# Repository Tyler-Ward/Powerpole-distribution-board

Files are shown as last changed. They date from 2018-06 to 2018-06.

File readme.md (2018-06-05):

# DC Distribution board for Anderson power-pole connectors.

This project is a fused DC distribution board.
The design uses Anderson powerpoles and ATC/ATO fuses which are in common use in amateur radio.
Unlike other DIY solutions this uses the powerpole 45A PCB contacts rather than short stubs of solid wire crimped to the powerpoles.

## Required parts

* 1*PCB - Should be made on a 2oz copper board.
* 4*Acrylic layers - one of each layer 3 at 6mm thick and one at 3mm thick
* 6*Anderson power pole connector pairs with 45A PCB connectors.
* 6*ATO fuse holders
* 6*330ohm resistors
* 6*3mm LEDs - bidirectional LEDs allow for fuse failure indication for both source and sinks
* 6*0.1uF Bypass capacitors

## Production files and Assembly instructions

Production files for the PCB and acrylic can be found in the releases list on github.
Assembly instructions can be found at https://www.suws.org.uk/wiki/Powerpole_Distribution

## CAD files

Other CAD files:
Cad/ATCFuse.ipt
Cad/AcrylicLowerBottom.ipt
Cad/AcrylicLowerCore.ipt
Cad/AcrylicUpperCore.ipt
Cad/AcrylicUpperTop.ipt
Cad/Assembled.iam
Cad/Capacitor.ipt
Cad/FuseHolder.ipt
Cad/LED3mm.ipt
Cad/PCB.ipt
Cad/PopulatedPCB.iam
Cad/PowerPole45.ipt
Cad/Powerpole45APCBStraight.ipt
Cad/PowerpolePairWContacts.iam
Cad/Resistor.ipt

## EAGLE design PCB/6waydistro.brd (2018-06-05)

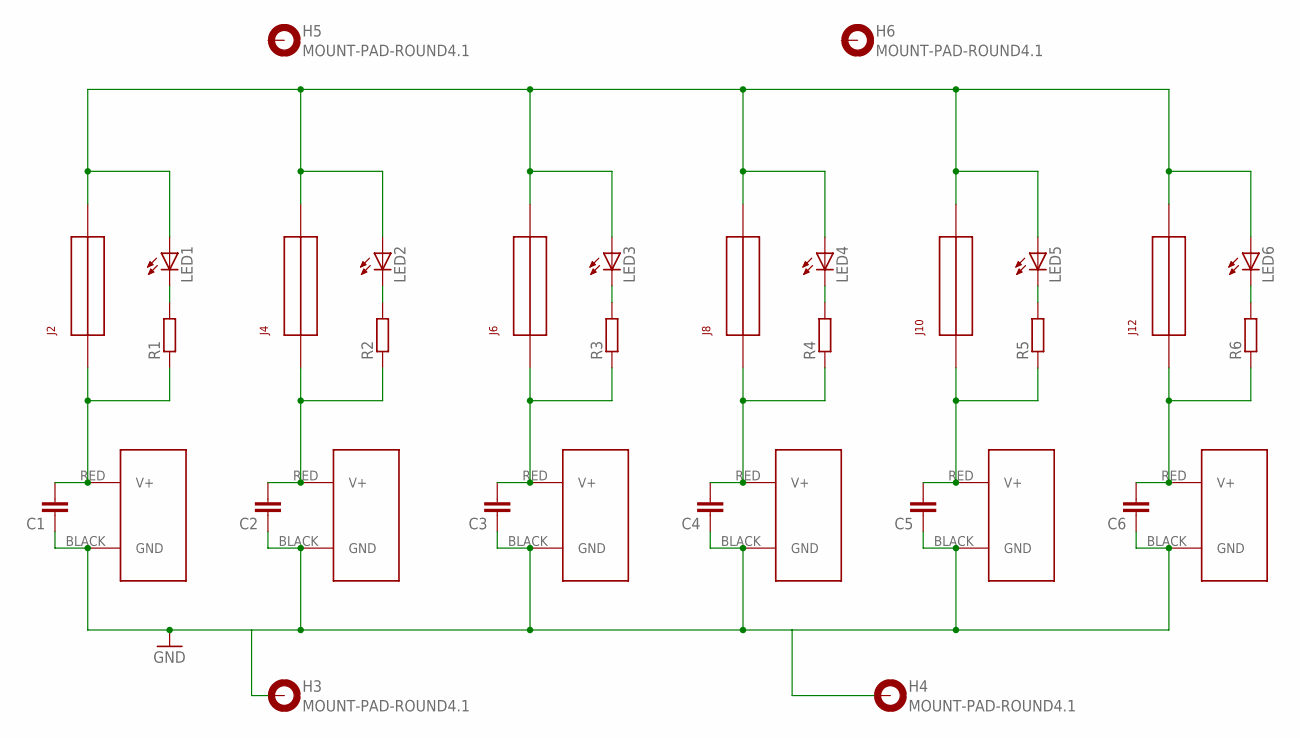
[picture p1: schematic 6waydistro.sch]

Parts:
C1, C2, C3, C4, C5, C6: C-EU050-025X075; C050-025X075
H3, H4, H5, H6: MOUNT-PAD-ROUND4.1; 4,1-PAD
J1, J3, J5, J7, J9, J11: POWERPOLE_POWER45A; POWERPOLE_PAIR_45A
J2, J4, J6, J8, J10, J12: FUSEATC; FUSE_ATC
LED1, LED2, LED3, LED4, LED5, LED6: LED3MM
R1, R2, R3, R4, R5, R6: R-EU_0204/7; 0204/7

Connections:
GND: C1.1, C2.1, C3.1, C4.1, C5.1, C6.1, H3.B4,1, H4.B4,1, J1.BLACK (GND), J3.BLACK (GND), J5.BLACK (GND), J7.BLACK (GND), J9.BLACK (GND), J11.BLACK (GND)
unnamed: LED2.K (C), R2.2
unnamed: LED1.K (C), R1.2
unnamed: LED3.K (C), R3.2
unnamed: LED4.K (C), R4.2
unnamed: LED5.K (C), R5.2
unnamed: LED6.K (C), R6.2
PPV1: C1.2, J1.RED (V+), J2.P$1, J2.P$2, R1.1
PPV2: C2.2, J3.RED (V+), J4.P$1, J4.P$2, R2.1
PPV3: C3.2, J5.RED (V+), J6.P$1, J6.P$2, R3.1
PPV4: C4.2, J7.RED (V+), J8.P$1, J8.P$2, R4.1
PPV5: C5.2, J9.RED (V+), J10.P$1, J10.P$2, R5.1
PPV6: C6.2, J11.RED (V+), J12.P$1, J12.P$2, R6.1
VCC: J2.P$3, J2.P$4, J4.P$3, J4.P$4, J6.P$3, J6.P$4, J8.P$3, J8.P$4, J10.P$3, J10.P$4, J12.P$3, J12.P$4, LED1.A, LED2.A, LED3.A, LED4.A, LED5.A, LED6.A

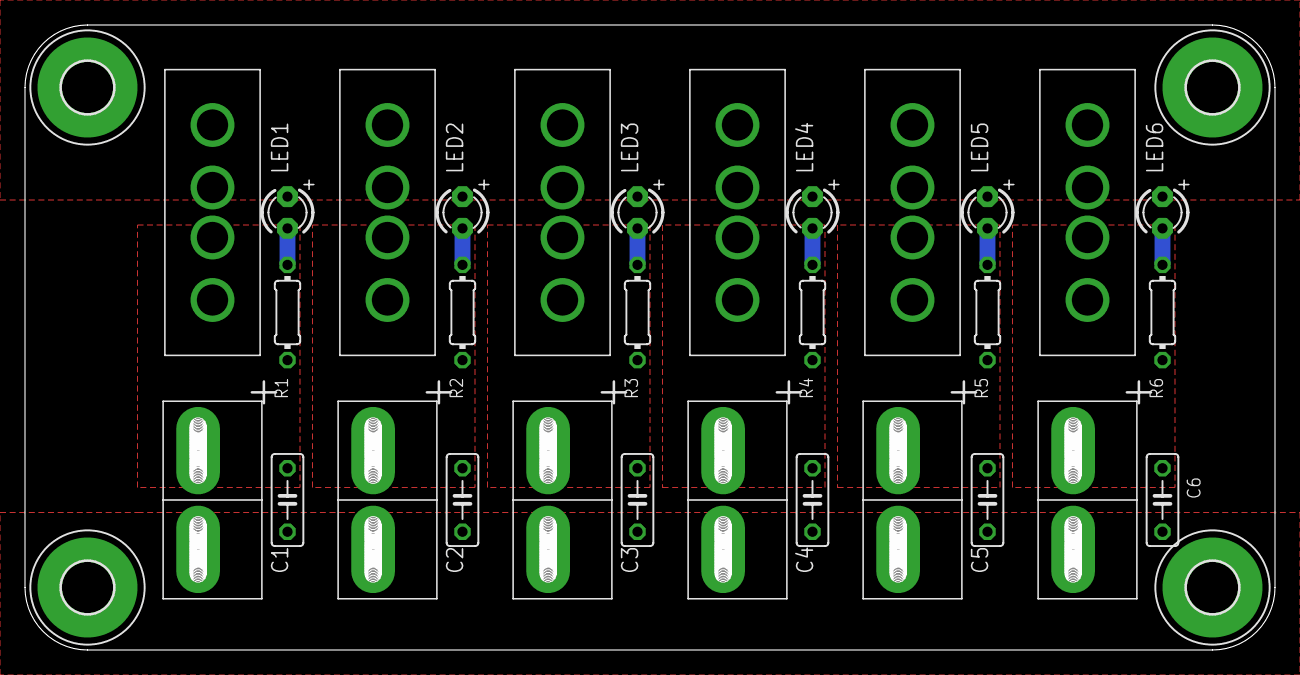
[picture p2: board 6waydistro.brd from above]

Board: 2 copper layers, 100.0 x 50.0 mm, 34 parts (0 on the bottom side), 14 nets.

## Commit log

2014-04-19 added draft version of powerpole distro board
    [6waydistro.brd, 6waydistro.sch]
2016-03-25 Removed wire inlet holes and adjusted board layout for acrylic case
    [6waydistro.brd, 6waydistro.sch]
2018-06-05 Minor silk screen edits to clean up component name placement
    [6waydistro.brd]
2018-06-05 Moved PCB files to separate directory
    [6waydistro.brd, 6waydistro.sch]
2018-06-05 Added Inventor cad files
    [ATCFuse.ipt, AcrylicLowerBottom.ipt, AcrylicLowerCore.ipt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]
